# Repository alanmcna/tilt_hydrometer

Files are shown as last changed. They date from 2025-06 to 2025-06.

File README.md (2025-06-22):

# Pico Tilt Hydrometer

Just like DIY? Yeah, me too. I'm all for supporting the existing market place offerings but I was keen to try this for myself (it didn't look too hard, spoiler - it wasn't) and there's no obvious local solution. 

I also keen to try:
* the 'impossible' - could a pi pico work with deepsleep mods?
* to use WIFI - water and 2.4ghz are not friends others use bluetooth - let's say I much prefer wifi and was keen to see if it was possible
  - that said WIFI is a hungry beast even 10s bursts are to much?

This is what I ended up with ...

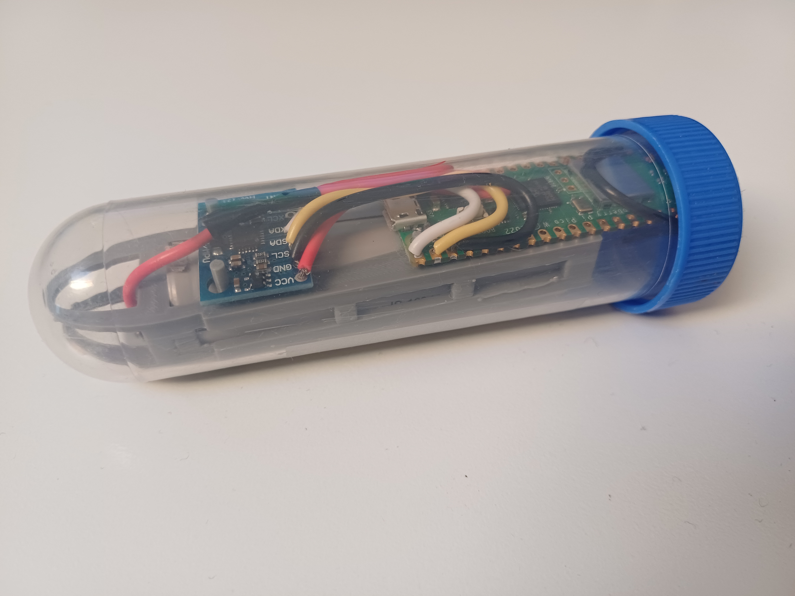
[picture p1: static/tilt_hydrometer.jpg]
Tilt Hydrometer - final product


Did it work .. yes, kindof .. more below.

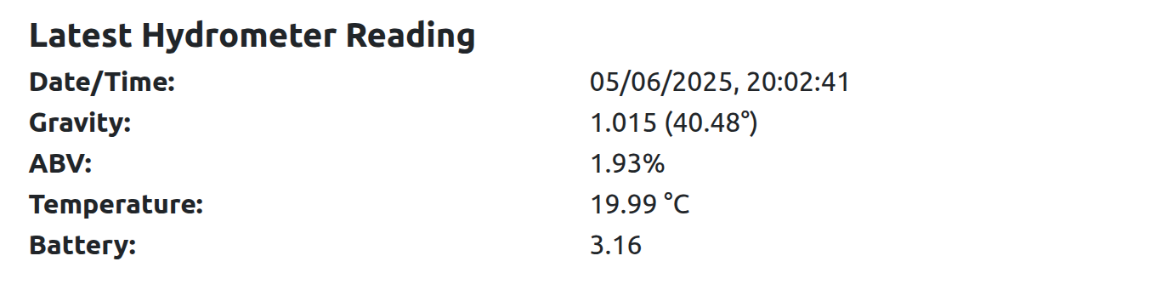
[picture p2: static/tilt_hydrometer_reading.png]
Tilt Hydrometer - test run results

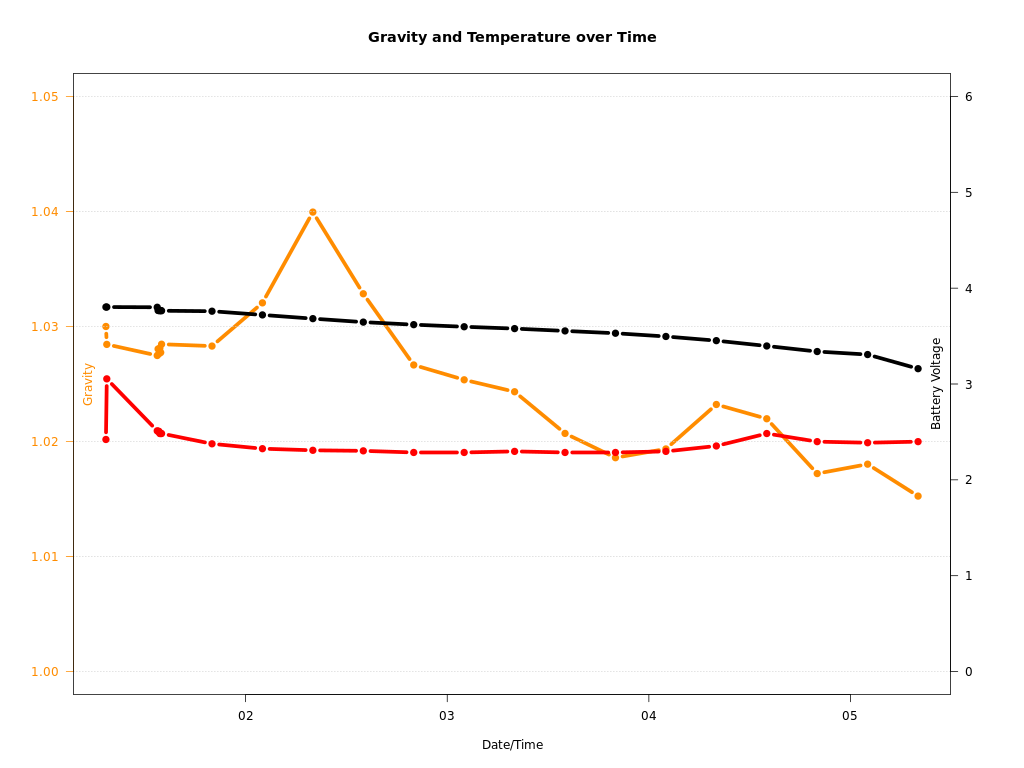
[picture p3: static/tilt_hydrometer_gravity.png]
Tilt Hydrometer - test gravity results


Spolier:
* WIFI - yes comms can work. The key was to have the wifi 'chip' touching the top of the cap so it clears the water surface ;)
* Deepsleep - jury is still out - I need more testing, so far can only get about 5 days @ 6 hourly readings - try again @ 12 hourly?

# PICO deepsleep 

Best article on this I have found here https://ghubcoder.github.io/posts/deep-sleeping-the-pico-micropython/

The base for this test is therefore https://github.com/ghubcoder/micropython-pico-deepsleep.git

# Hardware 

* Centrifuge Tube, 50mL with cap，round bottom - NOTE: 50ml is really too small, check the other tubes they're much bigger maybe 75-120ml - this provides more room for the electronics and tweaking base tilt angles.
  - Pre-forms would be ideal but found them hard to source in NZ without buying blind and hoping, not expensive but kinda key.
* Pico W (no headers)
* GY-9250 (MPU-9250) - 9-Axis Altitude + Gyro + Accelerator + Magnetometer Sensor Module
  - imo.py and vector3d.py - see https://github.com/micropython-IMU should probably use mpu9250.py in place of the generic imu
* Panasonic NCR18650BD 18650 Lithium Ion Battery https://www.simpower.co.nz/product/individual-cells-batteries/lithium-batteries/18650-batteries/panasonic-ncr18650bd-18650-lithium-ion-battery/
* 3d printed housing (with pegs) - see models folder for latest iteration
* Misc - Wires, Solder, etc
  - I also used some battery plates and springs that slide into the printed housing

# Software

* Pico running compiled 'deepsleep' firmware with main python scripts and libraries
  - See config for wifi connection and post end-point
  - default sleep is 2 minutes - the HTTP post response can change this to be 12-24 hours 
* Server to 'collect' the JSON post from the tilt hydrometer and log the data 
  - Flask
    - The JSON post response provides the sleep time
  - Python
  - R scipts for graphing

# Testing / Calibration

* Existing tilt hydrometer with varying sugar solutions (choose at what you need to get the polynomial to make sense - see below)
  - 1.000 Water
  - 1.010
  - 1.020
  - 1.030
  - 1.040
  - 1.050
* Plot them a choose a line of best fit (polynomial o3, or a straight line)
* Ideally have 15-20deg in water raising to close to 40+ in strong solution
  -  The denser the flatter
* Update https://github.com/alanmcna/tilt_hydrometer/blob/9d1fc7e8f4eefe1ddf18b97ff8b5bf052c9dcd0c/app.py#L39

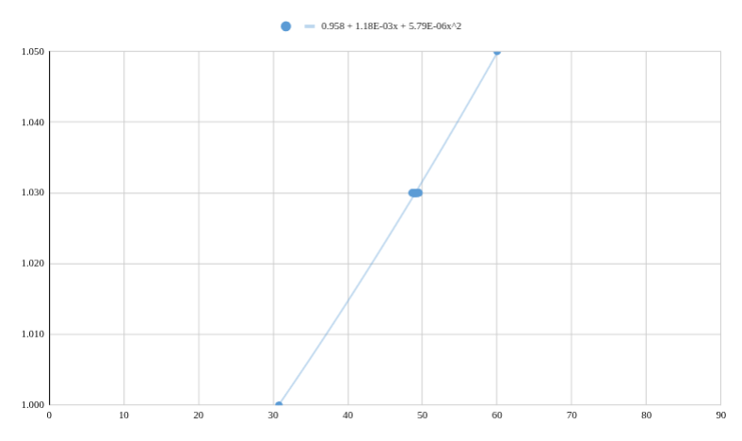
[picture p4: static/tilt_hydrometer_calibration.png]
Tilt Hydrometer - calibration


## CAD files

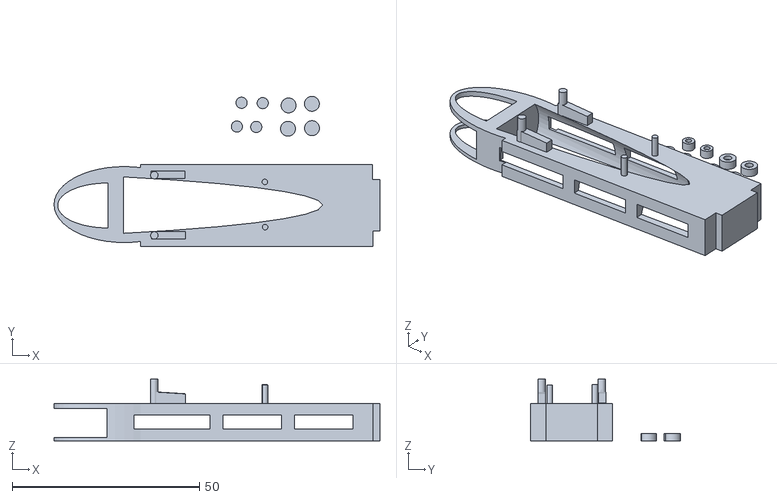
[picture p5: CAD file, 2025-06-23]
models/TubeFrame.stl
87.1 x 40.2 x 16.5

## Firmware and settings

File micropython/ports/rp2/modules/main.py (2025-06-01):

import machine
import utime
import picosleep


def get_vsys():
    conversion_factor = 3 * 3.3 / 65535

    try:
        # Make sure pin 25 is high.
        machine.Pin(25, mode=machine.Pin.OUT, pull=machine.Pin.PULL_DOWN).high()
        
        # Reconfigure pin 29 as an input.
        machine.Pin(29, machine.Pin.IN)
        
        vsys = machine.ADC(29)
        return vsys.read_u16() * conversion_factor

    finally:
        # Restore the pin state
        machine.Pin(29, machine.Pin.ALT, pull=machine.Pin.PULL_DOWN, alt=7)


def connect_to_wifi():
    import network
    import config

    try:
        wlan = network.WLAN(network.STA_IF)
        wlan.active(True)
        if not wlan.isconnected():
            wlan.connect(config.wifi_ssid,config.wifi_password)

            # don't try forever (we might be underwater ;)
            attempts = 5
            check = 0
            while not wlan.isconnected() and check < attempts:
                utime.sleep_ms(2000)
                check=check+1
        return wlan.isconnected()        
    except Exception as err:
        print(f"connect_to_wifi: unexpected {err=}, {type(err)=}")
        return False


def disable_wifi():
    import network

    try:
        wlan = network.WLAN(network.STA_IF)
        if wlan.isconnected(): #  maybe not necessary
            wlan.disconnect()

            attempts = 5
            check = 0
            while wlan.isconnected() and check < attempts:
                utime.sleep_ms(2000)
                check=check+1

        # do it anyway
        wlan.active(False)
        return not wlan.active()

    except Exception as err:
        print(f"disable_wifi: unexpected {err=}, {type(err)=}")
        return False

def get_mpu6050_data():
    from imu import MPU6050
    from math import atan2, sqrt, pi

    tilt = roll = temp = float("nan")

    try:
        # TODO consider re-testing with freq 200000 (400k is considered a max)
        i2c = machine.I2C(0, sda=machine.Pin(0), scl=machine.Pin(1), freq=400000)
        imu = MPU6050(i2c)

        # -1 * as we have the chip upside down :)
        tilt=-1 * atan2(imu.accel.x,sqrt((imu.accel.y*imu.accel.y)+(imu.accel.z*imu.accel.z))) * 180/pi 
        roll=atan2(imu.accel.y,sqrt((imu.accel.x*imu.accel.x)+(imu.accel.z*imu.accel.z))) * 180/pi
        temp=imu.temperature
    except Exception as err:
        print(f"get_mpu6050_data: unexpected {err=}, {type(err)=}")
        pass

    print(f"get_mpu6050_data: {tilt=}, {roll=}, {temp=}")
    return tilt, roll, temp

def post_sensor_data():
    import urequests
    import json
    import config

    time_to_sleep = config.time_to_sleep

    # Let's read battery voltage before we do anything.
    # TODO: do we need to handle exception here?
    bv = get_vsys()
    print(f"post_sensor_data: vsys {bv=}")

    LED = machine.Pin("LED", machine.Pin.OUT)
    LED.on()
    print("post_sensor_data: led on")

    try:
        if connect_to_wifi():
            print("post_sensor_data: connected to wifi")

            # TODO: maybe get 3 readings over X minutes and report the average?
            tilt, roll, temp = get_mpu6050_data()
            json_data =  { 'tilt': tilt, 'roll': roll, 'temp': temp, 'bv': bv }
        
            r = urequests.post(config.http_api, data=json.dumps(json_data), timeout=15)

            if r.status_code == 200:
                print(f"post_sensor_data: {r.status_code=}, {r.text=}")
                r_json = json.loads(r.text)
                if 'OK' in r_json:
                    # Let's be sensible - at least 1 minute but less than or equal to 1 day
                    if r_json['OK'] >= 60 and r_json['OK'] <= 86400: 
                        time_to_sleep = r_json['OK']
                        print(f"post_sensor_data: updating {time_to_sleep=} (seconds) from POST response")
                    # TODO - update POST url based on response JSON also
            else:
                print(f"post_sensor_data: {r.status_code=}")

        if disable_wifi():
            print("post_sensor_data: disconnected from wifi")
        else:
            print("post_sensor_data: unable to disconnect to wifi")
            
    except Exception as err:
        print(f"post_sensor_data: unexpected {err=}, {type(err)=}")
        pass

    LED.off()
    print("post_sensor_data: led off")

    return time_to_sleep

### MAIN ###

# Allow some seconds for USB serial just in case it's connected for debugging
utime.sleep_ms(10000)

while True:
    time_to_sleep = post_sensor_data()

    try:
        # put the device to sleep for 3600 seconds (1 hr)
        print(f"main: about to picosleep for {time_to_sleep=} seconds")
        utime.sleep_ms(2000) # give it time to print the logging

        picosleep.seconds(time_to_sleep)
    except Exception as err:
        print(f"main: unexpected {err=}, {type(err)=}")

        utime.sleep_ms(time_to_sleep * 1000)

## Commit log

2025-06-01 First commit - base flask site working with firmware push every 6 hours - battery life still being tested.
    [TubeFrame4.1.stl]
2025-06-22 Adding calibration text and image
2025-06-22 Adding code reference to calibration
2025-06-23 Updating the model
    [TubeFrame.stl, TubeFrame4.1.stl]
